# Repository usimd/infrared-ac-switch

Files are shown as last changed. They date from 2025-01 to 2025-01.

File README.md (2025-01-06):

# IR-based remote AC switch
This projects aims to remote control an AC power socket. It features two PCBs with one being an IR emitter controlled by an AC input and a receiver/switch that turns on power if the IR signal is received.

The motivation to build this was an existing power outlet at the ceiling of our kitchen being controlled by a wall switch which I wanted to use to switch another lighting device in the room powered from a wall socket.
The emitter is mounted at the ceiling outlet and turned on once the wall switch was used. The receiver then turns on the lighting device at the other end of the room as long as the emitter keeps signalling.

## Circuits
Both circuits implement a capacitor power supply, as only a few mA of current are reqired to either drive an LED and a signal generator (emitter) or the IR receiver and a solid state relay (switch). The capacitor PSU is tolerant up to 230V AC.

The IR signal is pulsed at 38kHz and can be tuned using a potentiometer on the emitter's side. The signal is generated using a simple 555 circuit.

If you want to enclose the receiver/switch, there's a [case available to 3D print](case/case.3mf).

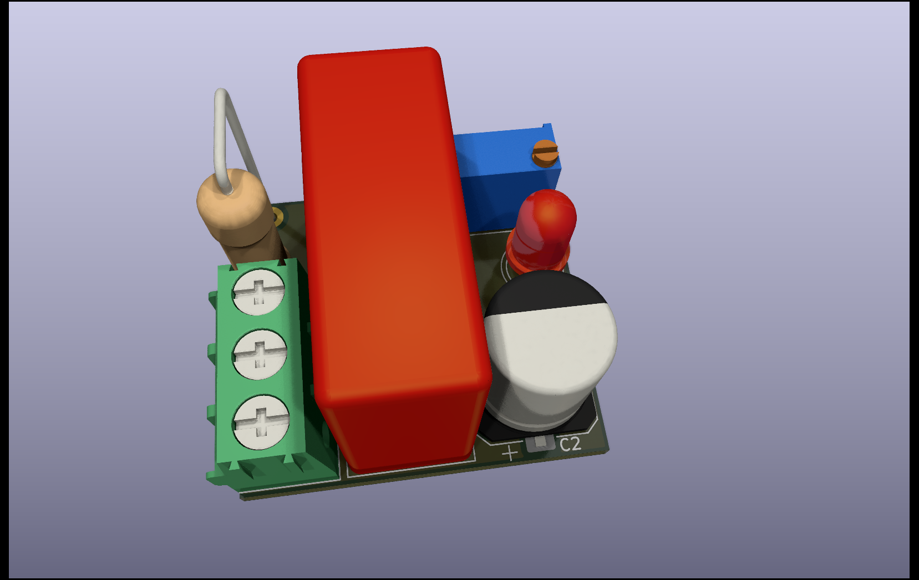
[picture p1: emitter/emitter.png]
emitter

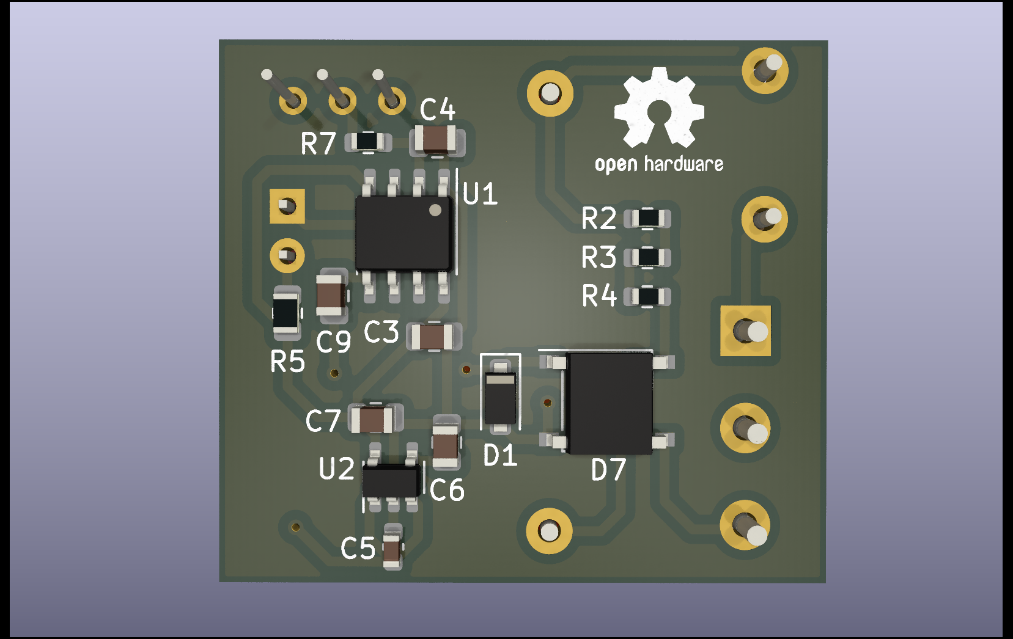
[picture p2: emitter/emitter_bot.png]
emitter_bot

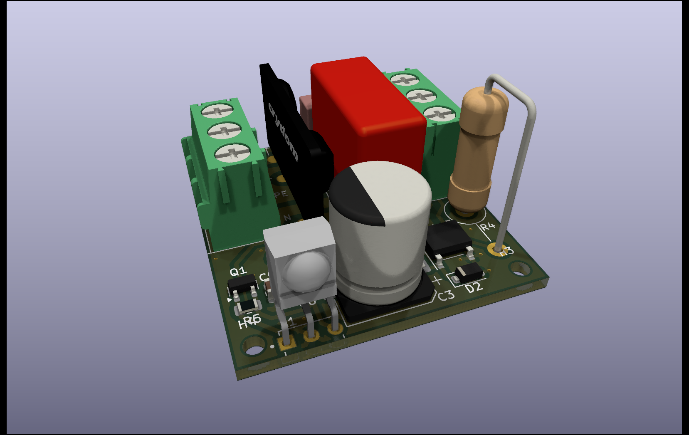
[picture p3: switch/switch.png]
switch


## Safety note
I am no electronics specialist and can not guarantee for the safety of these devices. If you want to build these for yourself be aware that you'll be working with mains voltage which can be potentially deadly when handled without care! Use at your own risk.

The PCBs have been prototyped at AISLER:
* [switch](https://aisler.net/p/HPFIOOUA)
* [emitter](https://aisler.net/p/JRNHJFBC)

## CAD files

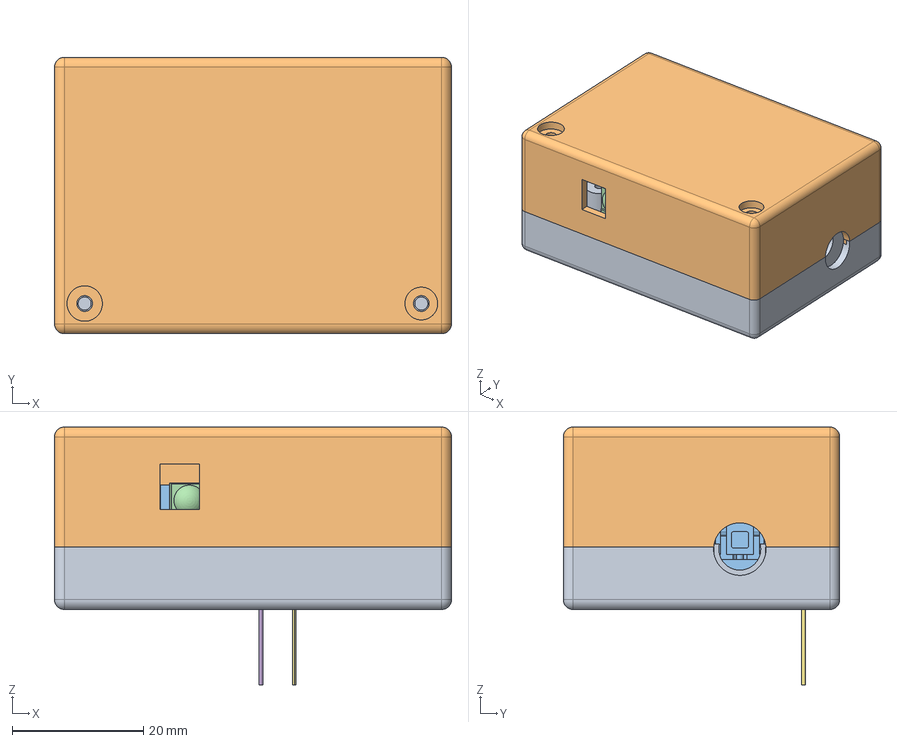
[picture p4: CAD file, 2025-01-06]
case/case.FCStd
60.5 x 42.1 x 39.3 mm
Bottom final
Top final
Pcb_ec94
topPads_ec095
topTracks_ec095
topZones_ec095
botPads_ec095
botTracks_ec095
botZones_ec095
U2_SOT_23_5_863a62e270d0
J2_TerminalBlock_Phoenix_PT_15_3_50_H_1x03_P500mm_Horizontal_8e5a26944e39 x 2
GO-100184
GO-100184.032
GO-100184.033
GO-100184.034
C3_CP_Elec_10x125_846d0c8a04ca
C6_C_0805_2012Metric_19e55b627c06 x 2
R4_R_Axial_DIN0516_L155mm_D50mm_P762mm_Vertical_b73bf4800ee1
C1_C_Rect_L180mm_W80mm_P1500mm_FKS3_FKP3_27f843e74350
D1_Diode_Bridge_Diotec_ABS_f9176e805c13
D2_D_SOD_123F_6e59eb8ac936
C4_C_0603_1608Metric_3f43c1c5a1fa
R3_R_0805_2012Metric_d859491b059c x 4
Q1_SOT_23_3900012b851c

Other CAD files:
case/case.3mf

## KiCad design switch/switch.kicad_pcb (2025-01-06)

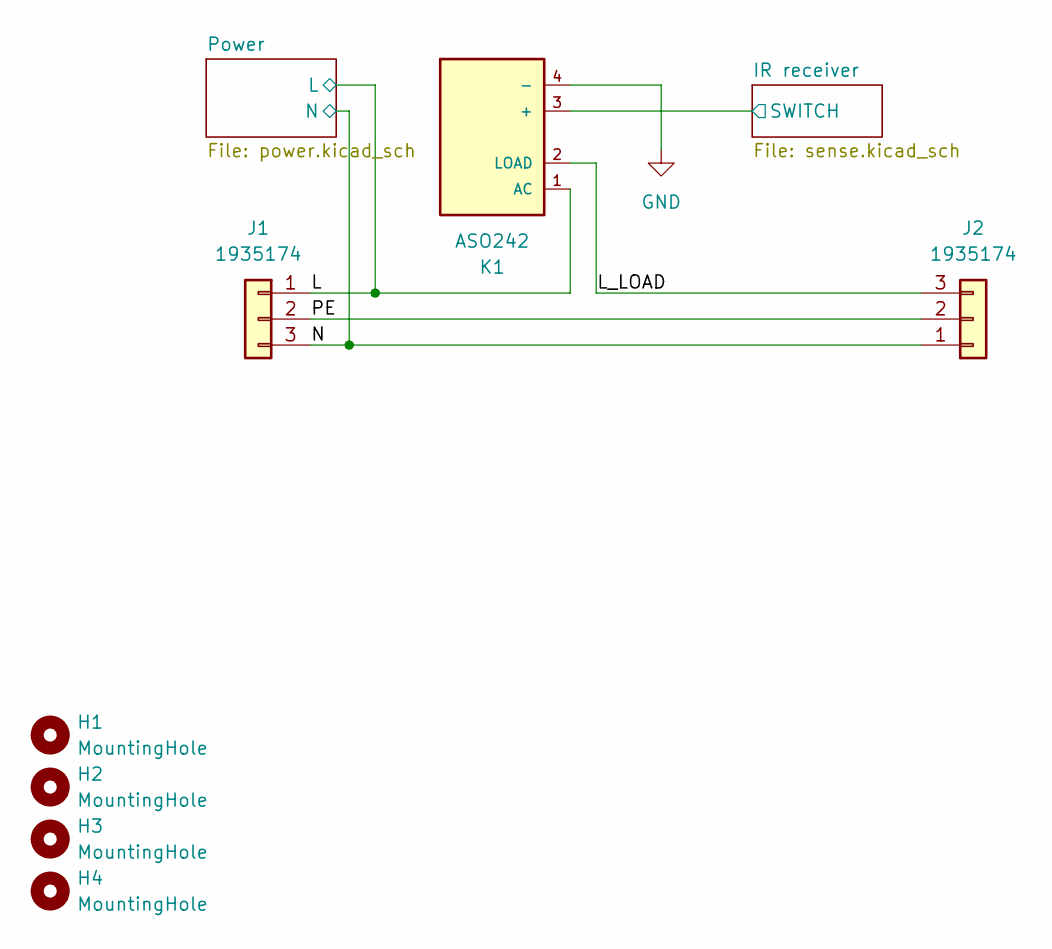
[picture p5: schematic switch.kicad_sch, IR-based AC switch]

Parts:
H1, H2, H3, H4: MountingHole; MountingHole_2.2mm_M2_ISO14580
J1, J2: 1935174; TerminalBlock_Phoenix_PT-1,5-3-5.0-H_1x03_P5.00mm_Horizontal; MPN1 Phoenix Contact:1935174
K1: ASO242; MPN ASO242; DigiKey_Part_Number CC1336-ND

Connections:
/IR receiver/SWITCH: K1.3 (+); also elsewhere on the board
/L: J1.1, K1.1 (AC); also elsewhere on the board
/L_LOAD: J2.3, K1.2 (LOAD)
/N: J1.3, J2.1; also elsewhere on the board
/PE: J1.2, J2.2
GND: K1.4 (-); also elsewhere on the board

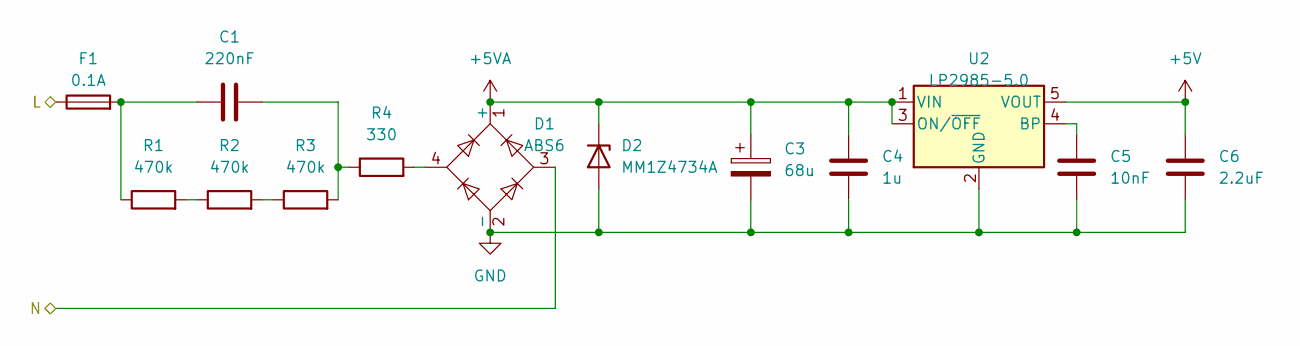
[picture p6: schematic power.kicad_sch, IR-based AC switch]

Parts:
C1: 220nF; C_Rect_L18.0mm_W8.0mm_P15.00mm_FKS3_FKP3; MPN1 WIMA:MKX2AW32205B00KSSD
C3: 68u; CP_Elec_10x12.5; MPN1 Panasonic:50SVPF68M
C4: 1u; C_0603_1608Metric; MPN1 Kyovera AVX:0603YD105KAT2A
C5: 10nF; C_0805_2012Metric
C6: 2.2uF; C_0805_2012Metric
D1: ABS6; Diode_Bridge_Diotec_ABS; MPN1 Diotec:ABS6
D2: MM1Z4734A; D_SOD-123F; MPN1 Diotec:MM1Z4734A
F1: 0.1A; Fuse_Littelfuse_395Series; MPN1 ESKA:883007-1
R1, R2, R3: 470k; R_0805_2012Metric_Pad1.20x1.40mm_HandSolder
R4: 330; R_Axial_DIN0516_L15.5mm_D5.0mm_P7.62mm_Vertical; MPN1 Vitrohm:CRF253-45T330R
U2: LP2985-5.0; SOT-23-5; MPN1 Texas Instruments:LP2985-50DBVR

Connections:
+5V: C6.1, U2.5 (VOUT); also elsewhere on the board
+5VA: C3.1, C4.1, D1.1 (+), D2.1 (K), U2.1 (VIN), U2.3 (ON/~OFF)
/L: F1.1; also elsewhere on the board
/N: D1.3; also elsewhere on the board
GND: C3.2, C4.2, C5.2, C6.2, D1.2 (-), D2.2 (A), U2.2 (GND); also elsewhere on the board
unnamed: C1.1, F1.2, R1.1
unnamed: C1.2, R3.2, R4.1
unnamed: D1.4, R4.2
unnamed: R1.2, R2.1
unnamed: R2.2, R3.1
unnamed: C5.1, U2.4 (BP)

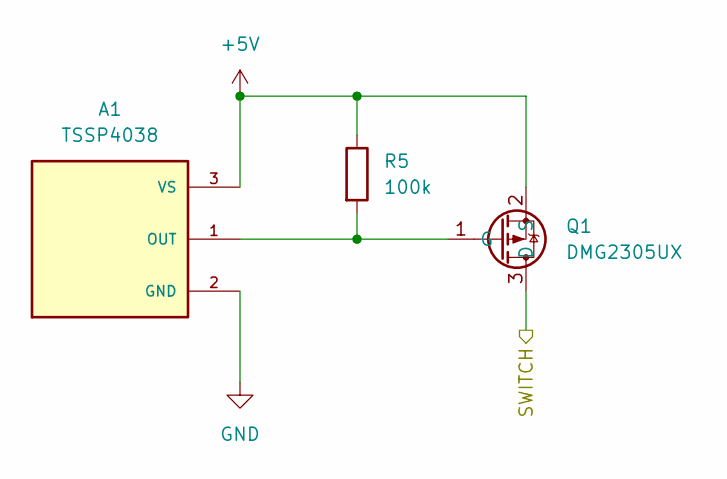
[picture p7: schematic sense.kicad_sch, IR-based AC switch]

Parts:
A1: TSSP4038; XDCR_TSSP4038; PARTREV 2.3
Q1: DMG2305UX; SOT-23; MPN1 Diodes:DMG2305UX-13
R5: 100k; R_0805_2012Metric

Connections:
+5V: A1.3 (VS), Q1.2 (S), R5.1; also elsewhere on the board
/IR receiver/SWITCH: Q1.3 (D); also elsewhere on the board
GND: A1.2 (GND); also elsewhere on the board
unnamed: A1.1 (OUT), Q1.1 (G), R5.2

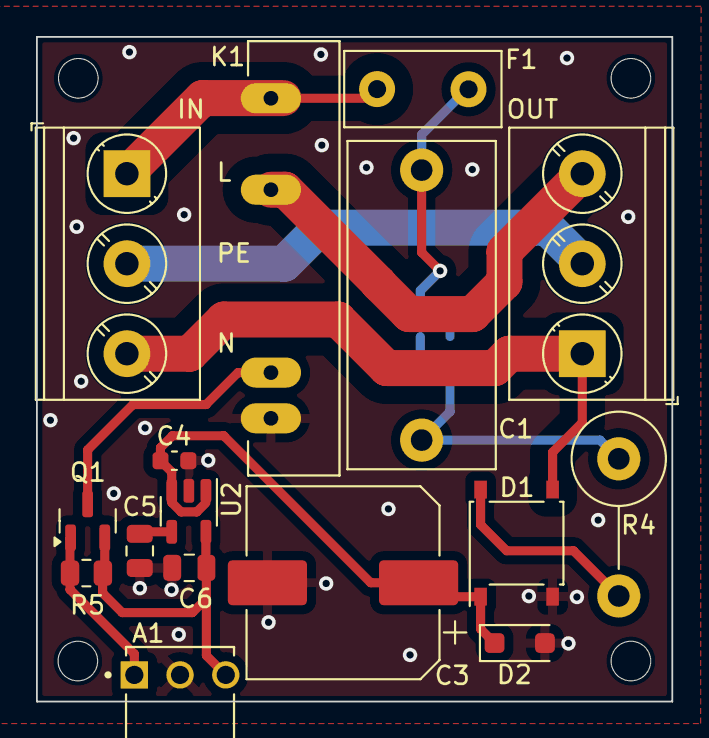
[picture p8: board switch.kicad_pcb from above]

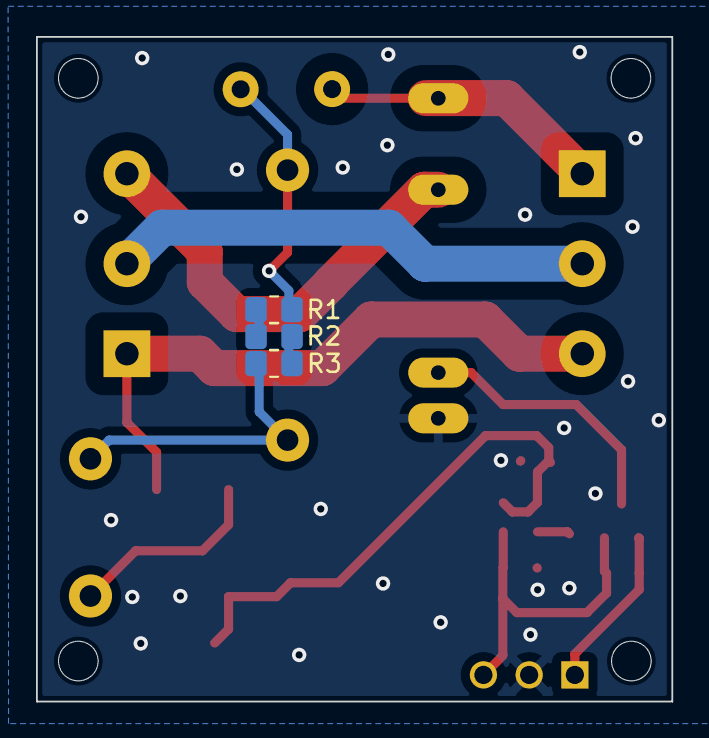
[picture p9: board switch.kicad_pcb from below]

Board: 2 copper layers, 35.3 x 36.9 mm, 23 parts (3 on the bottom side), 15 nets.

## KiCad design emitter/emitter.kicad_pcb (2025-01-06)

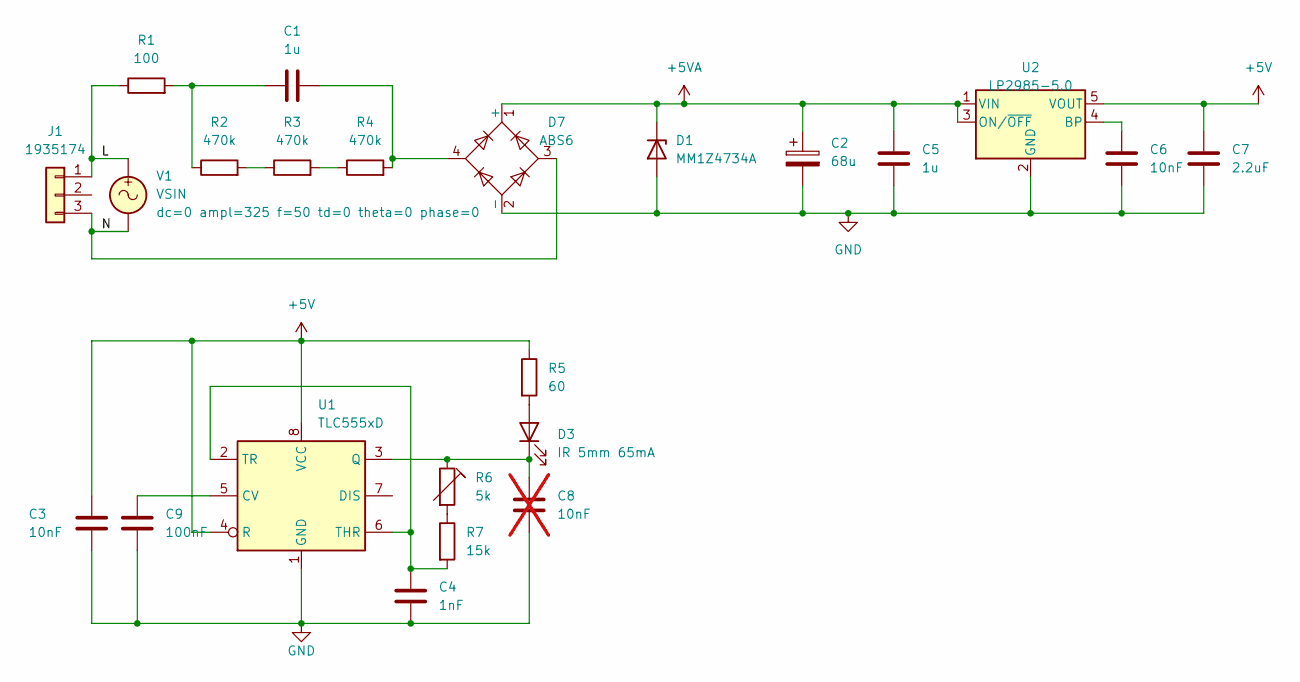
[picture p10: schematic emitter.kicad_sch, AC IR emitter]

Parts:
C1: 1u; C_Rect_L26.5mm_W10.5mm_P22.50mm_MKS4; MPN1 WIMA:MKX2AW41005I00KSSD
C2: 68u; CP_Elec_10x12.5; MPN1 Panasonic:50SVPF68M
C3, C6: 10nF; C_0805_2012Metric
C4: 1nF; C_0805_2012Metric
C5: 1u; C_0603_1608Metric
C7: 2.2uF; C_0805_2012Metric
C8: 10nF; C_0805_2012Metric; not fitted
C9: 100nF; C_0805_2012Metric
D1: MM1Z4734A; D_SOD-123F; MPN1 Diotec:MM1Z4734A
D3: IR 5mm 65mA; LED_D5.0mm; MPN1 Everlight:IR333
D7: ABS6; Diode_Bridge_Diotec_ABS; MPN1 Diotec:ABS6
J1: 1935174; TerminalBlock_Phoenix_PT-1,5-3-5.0-H_1x03_P5.00mm_Horizontal; MPN1 Phoenix Contact:1935174
R1: 100; R_Axial_DIN0516_L15.5mm_D5.0mm_P7.62mm_Vertical; MPN1 Vitrohm:CRF250JT-73-100RYY
R2, R3, R4: 470k; R_0603_1608Metric
R5: 60; R_0805_2012Metric; MPN1 Weltron:092305BTC
R6: 5k; Potentiometer_Bourns_3296W_Vertical; MPN1 Weltron:001045026338
R7: 15k; R_0603_1608Metric
U1: TLC555xD; SOIC-8_3.9x4.9mm_P1.27mm; MPN1 Texas Instruments:TLC555CDR
U2: LP2985-5.0; SOT-23-5; MPN1 Texas Instruments:LP2985-50DBVR
V1: VSIN

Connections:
+5V: C3.1, C7.1, R5.1, U1.4 (R), U1.8 (VCC), U2.5 (VOUT)
+5VA: C2.1, C5.1, D1.1 (K), D7.1 (+), U2.1 (VIN), U2.3 (ON/~OFF)
/L: J1.1, R1.1, V1.1
/N: D7.3, J1.3, V1.2
GND: C2.2, C3.2, C4.2, C5.2, C6.2, C7.2, C8.2, C9.2, D1.2 (A), D7.2 (-), U1.1 (GND), U2.2 (GND)
unnamed: C1.1, R1.2, R2.1
unnamed: C1.2, D7.4, R4.2
unnamed: D3.2 (A), R5.2
unnamed: C8.1, D3.1 (K), R6.1, U1.3 (Q)
unnamed: R2.2, R3.1
unnamed: R3.2, R4.1
unnamed: R6.2, R7.1
unnamed: C9.1, U1.5 (CV)
unnamed: C4.1, R7.2, U1.2 (TR), U1.6 (THR)
unnamed: C6.1, U2.4 (BP)

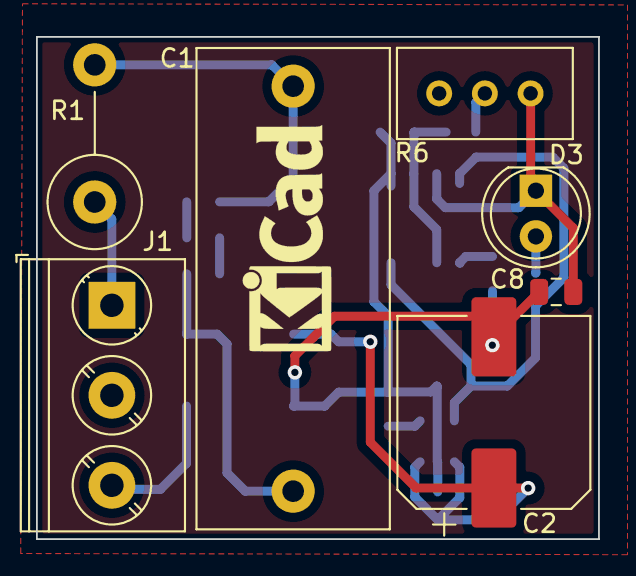
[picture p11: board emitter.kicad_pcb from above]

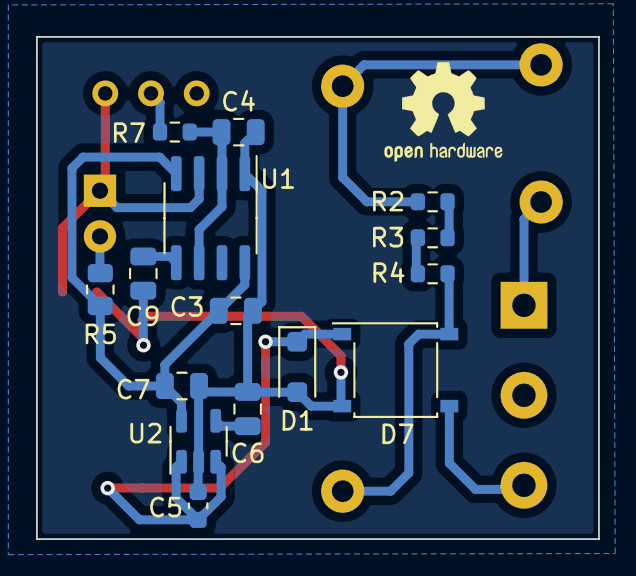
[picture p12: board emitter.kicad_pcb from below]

Board: 2 copper layers, 31.2 x 27.9 mm, 22 parts (15 on the bottom side), 15 nets.

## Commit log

2023-11-12 Initial import
    [emitter.kicad_pcb, emitter.kicad_sch, sensata-aso-series-100101-drawing.step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]
2024-11-03 Updated rev
    [82691Mold_CD.stp, 82700Mold_DA.stp, 82715Mold_SK.stp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]
2025-01-06 Add case
    [82691Mold_CD.stp, 82700Mold_DA.stp, 82715Mold_SK.stp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]
2025-01-06 Add PCB images
2025-01-06 Fix issues
    [power.kicad_sch, sense.kicad_sch, switch.kicad_pcb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]
